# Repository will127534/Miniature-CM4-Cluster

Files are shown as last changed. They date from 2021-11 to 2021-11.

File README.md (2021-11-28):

# Miniature CM4 Cluster
A dense Cluster for four Raspberry Pi 4 Compute Module 4

Here is the main description: [https://will127534.github.io/Miniature-CM4-Cluster/](https://will127534.github.io/Miniature-CM4-Cluster/)

## System Arch


## Files
* ClusterHat - PCB files for CLuster Hat
* CM4Card - PCB files for CM4 Card
* Software - Code for Raspberry Pi Pico & I2C EEPROM image for USB Hub
* Mechanical - STL for the dual 4cm fan frame 

## Notes
* RTL8367N Datasheet comes from here https://github.com/libc0607/Realtek_switch_hacking
* Designed with KiCad 5.99.0-12597-g9f841da98e

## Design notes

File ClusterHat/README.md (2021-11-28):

# CM4-Cluster-Hat
The PCB board files for the main hat

## Notes
* The measurement of node's input current is on the CM4 Card (tps2420 efuse current monitor output)
* I tried to use GPIO pin straps to set up USB Hub, but there is no such configuration that works, so I end up placing an I2C EEPROM that contains the settings. There are three jumpers at the back of the board that connect that EEPROM to RPI & hold the reset of USB HUB, so you can/need to flash the EEPROM image the first time.
    * Also note that because reversing the polarity of USB data eases the layout, all of the device's USB polarity is swapped and configured as such, so that is why in the sch the P/N is reversed.
    * There might be some issue with the LED indicator on the USB Hub.
* You could connect the MII interface to RPI, but I'm not sure how to use it to turn it into a managed switch.
* And just to remind you that **the M.2 connector on this board is a non-standard pinout**, please don't attach anything other than the CM4 Card.
 
## Preview



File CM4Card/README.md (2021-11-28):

# CM4 Card
The PCB board files for the CM4 Card

## Notes
* Because the interconnector is using M.2, the board thickness is limited to 0.8mm
* Yes, I did put most of the components under CM4. The SD card slot is 1.45mm in height. It is fine with the 3mm connector height for the CM4.
* The address for TMP117 is depend on the Cluster Hat.

## Preview



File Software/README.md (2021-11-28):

# Software
Pico Software and USB hub EEPROM image

## Pico Software

The code is a slightly modified version of the adc_console.c from the Pico C/C++ SDK, the main changes are adding more commend to control the GPIO pins and reading current measurement.  
```
Selecting the channel/node, send c + [node number]
Enabling the power (Pull EN pin on the CM4 high), send e
Disabling the power (Pull EN pin on the CM4 low), send d
Asserting USB boot pin, send U
Disasserting USB boot pin, send u
Resetting the CM4 via RUN pin (holding it low for 100ms), send r 
Reading the ADC raw and voltage measurement, send s
Reading all the CM4's current, send a
```

## USB hub configuring

Apart from the name customization, the USB pins are configured to be flipped for all the downstream ports that are used.

To flash the binary, you can use the following command after you connect the EEPROM to RPI.
```

```

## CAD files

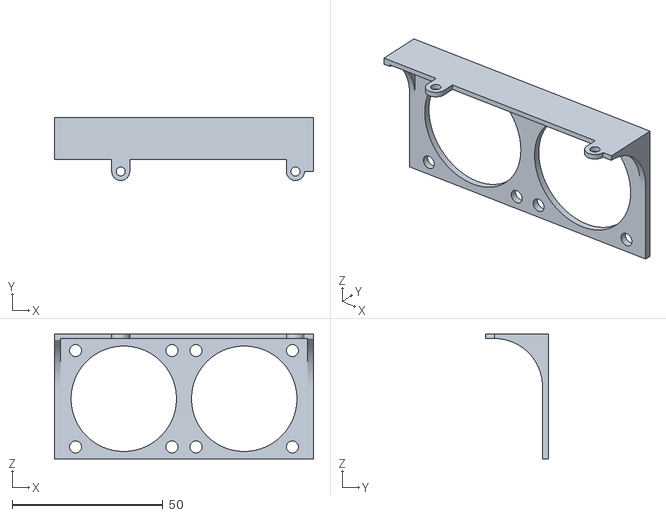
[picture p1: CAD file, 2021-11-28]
Mechanical/ClusterFan.stl
86.0 x 21.0 x 41.5

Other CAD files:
Mechanical/ClusterFan.f3d

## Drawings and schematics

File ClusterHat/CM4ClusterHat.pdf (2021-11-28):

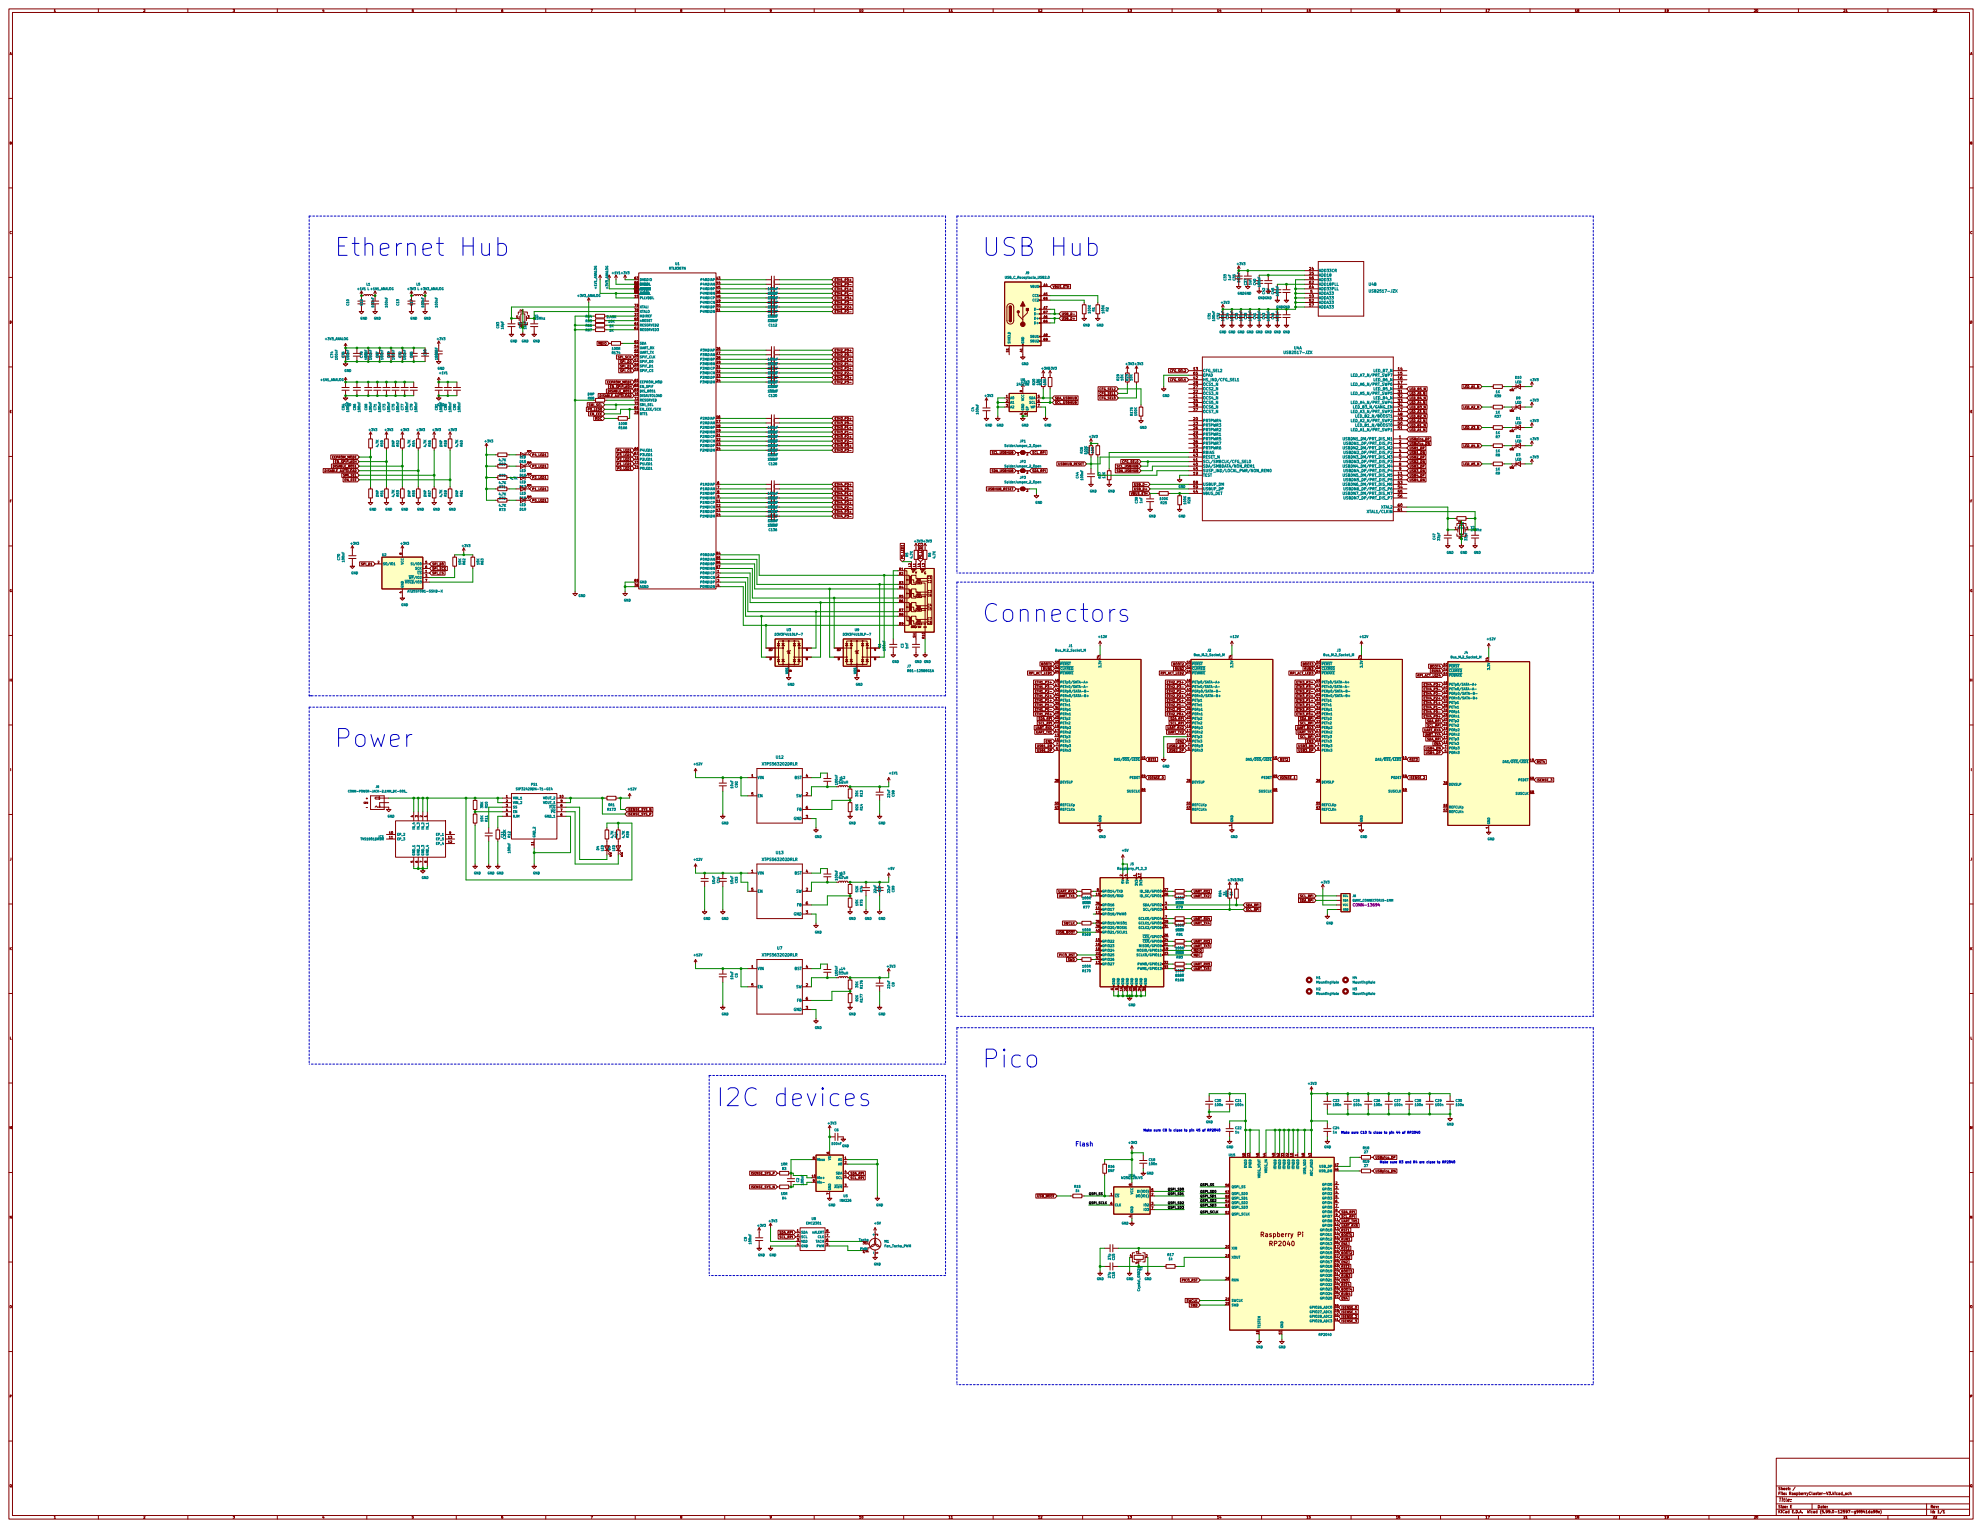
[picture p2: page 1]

LED GND GND 27p C15 GND

Make sure C8 is close to pin 45 of RP2040

Make sure C10 is close to pin 44 of RP2040

Make sure R3 and R4 are close to RP2040 Flash

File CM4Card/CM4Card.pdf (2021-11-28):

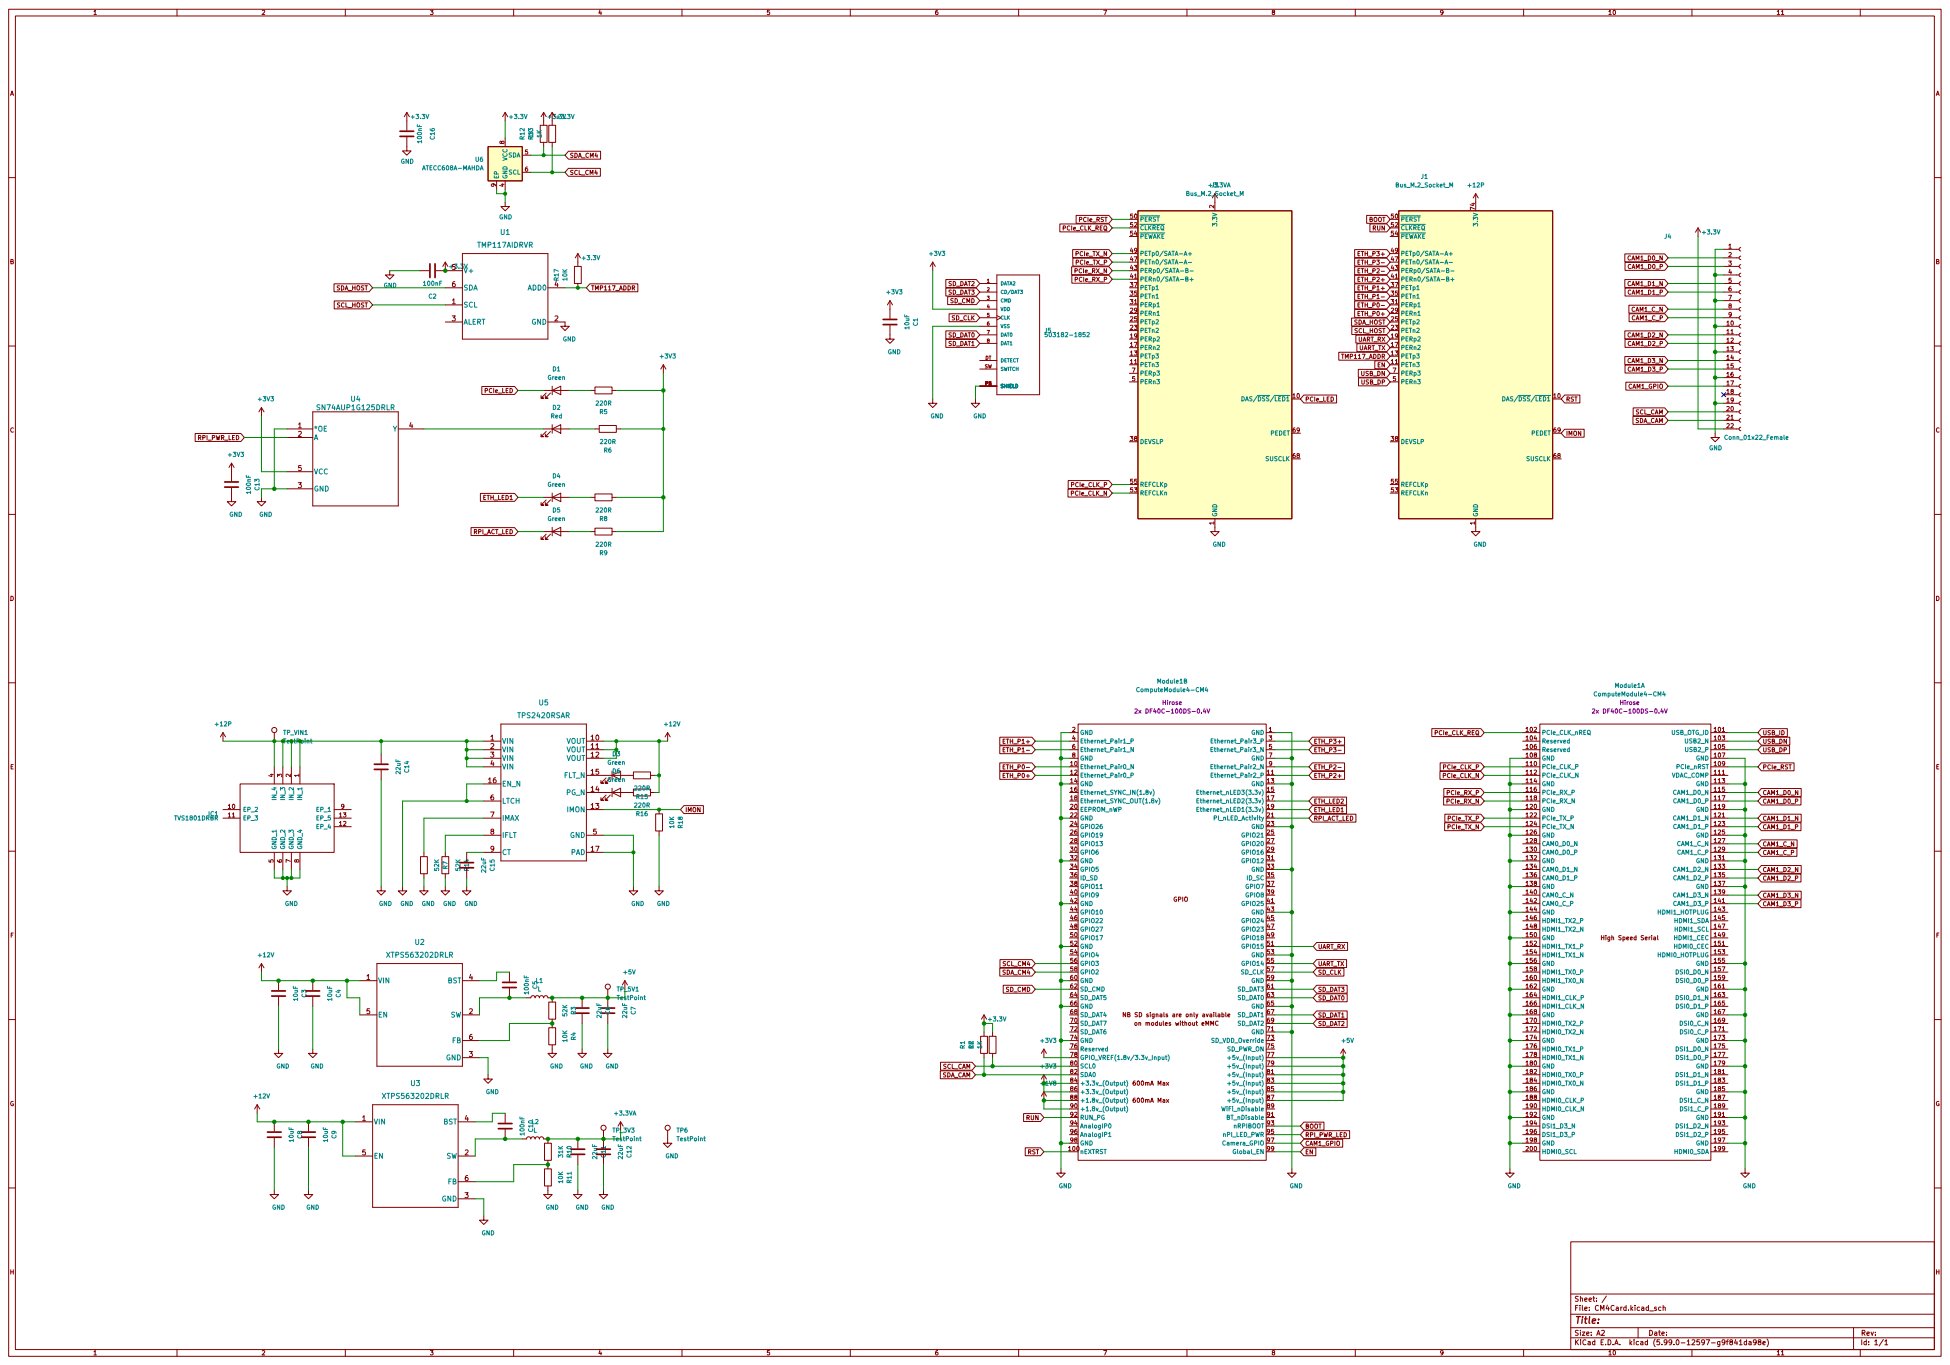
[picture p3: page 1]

2 PETn2 23 PETp2 25 PERn1 29 PERp1 31 PETn1 35 PETp1 37 DEVSLP 38 PERn0/SATA-B+ 41 PERp0/SATA-B- 43 PETn0/SATA-A- 47 PETp0/SATA-A+ 49 PERn3 5 ~{PERST} 50 ~{CLKREQ} 52 REFCLKn 53

600mA Max 600mA Max NB SD signals are only available

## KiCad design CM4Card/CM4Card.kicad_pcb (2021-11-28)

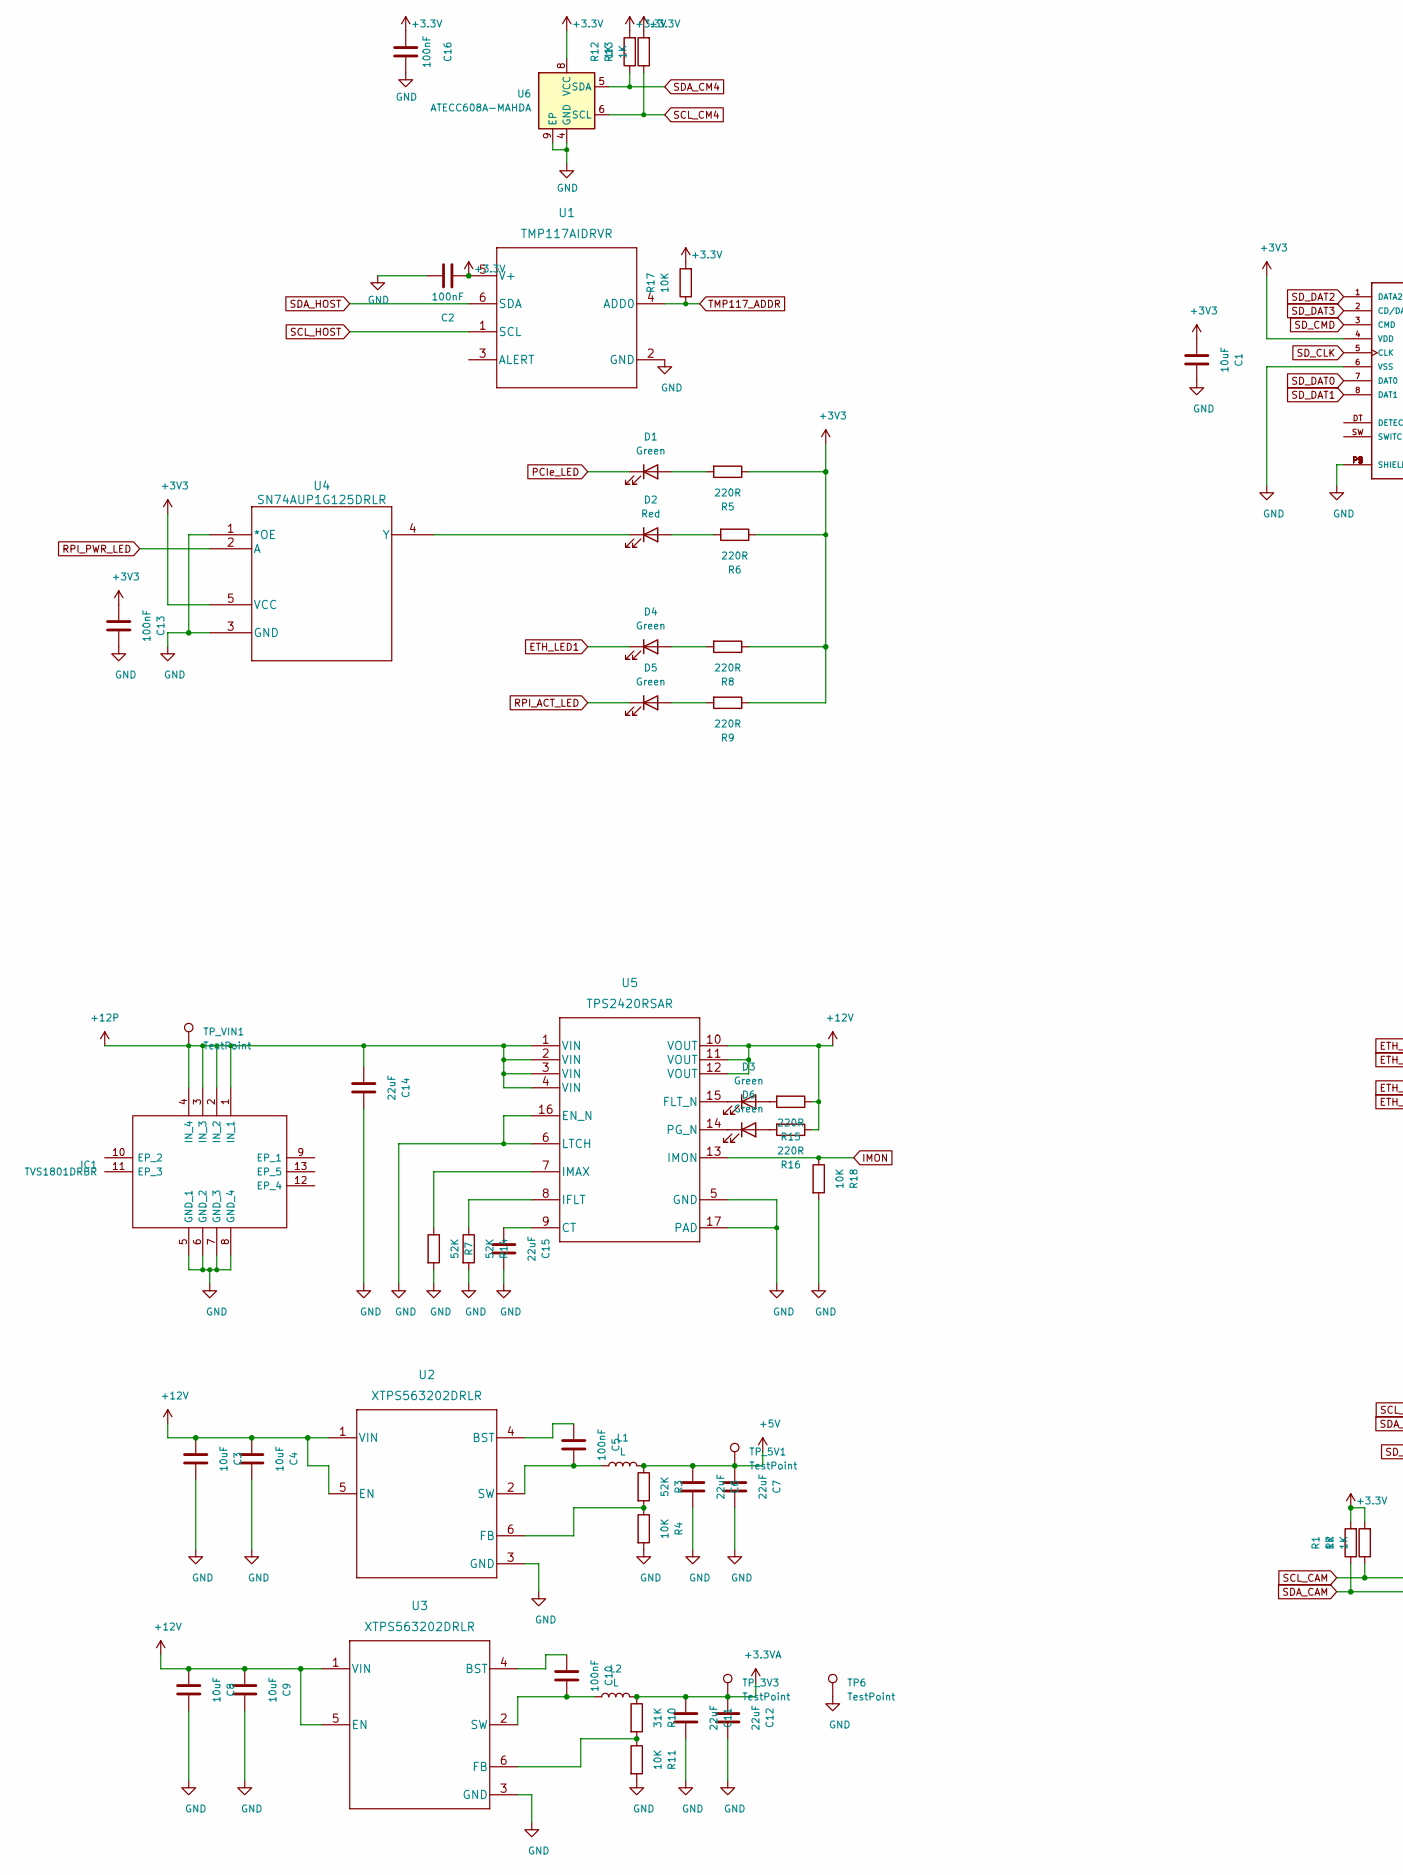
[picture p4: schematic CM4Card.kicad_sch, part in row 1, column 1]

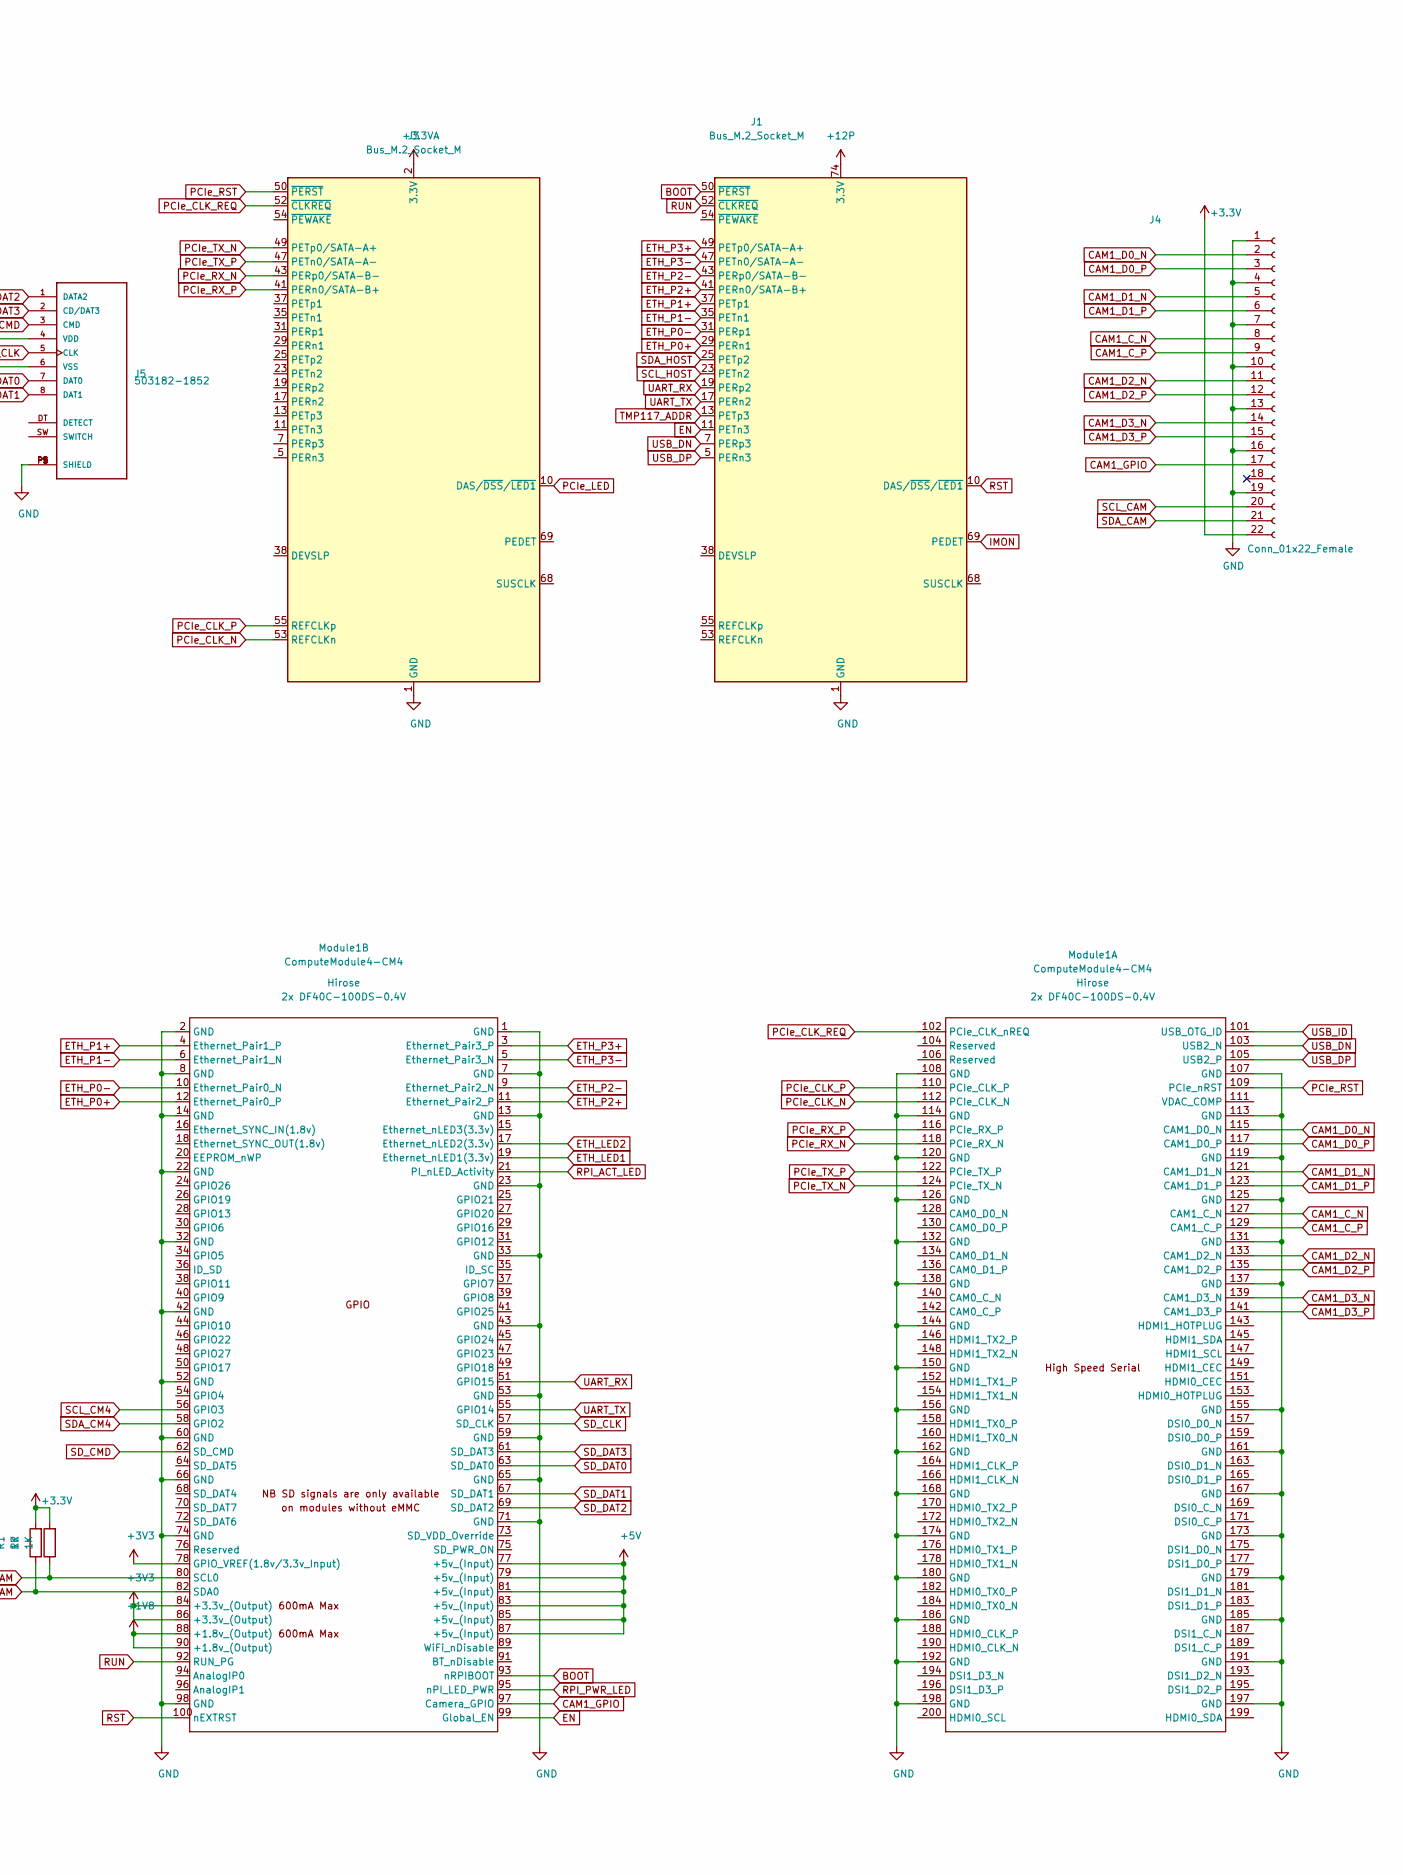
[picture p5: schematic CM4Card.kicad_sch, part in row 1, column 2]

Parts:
C1, C3, C4, C8, C9: 10uF; C_0805_2012Metric
C2, C5, C10, C13, C16: 100nF; C_0402_1005Metric
C6, C7, C11, C12: 22uF; C_0805_2012Metric
C14, C15: 22uF; C_0402_1005Metric
D1, D3, D4, D5, D6: Green; LED_0603_1608Metric
D2: Red; LED_0603_1608Metric
IC1: TVS1801DRBR; TPS73601DRBR; Mouser Part Number 595-TVS1801DRBR
J1: Bus_M.2_Socket_M; NGFF_M
J3: Bus_M.2_Socket_M; 1-2199230-6
J4: Conn_01x22_Female; Hirose_FH12-22S-0.5SH_1x22-1MP_P0.50mm_Horizontal; Part Description 22 Position FFC, FPC Connector Contacts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
J5: 503182-1852; MOLEX_503182-1852
L1, L2: L; L_Coilcraft_XAL5030
Module1: ComputeModule4-CM4; Raspberry-Pi-4-Compute-Module
R1, R2, R12, R13: 1K; R_0402_1005Metric
R3, R7, R14: 52K; R_0402_1005Metric
R4, R11, R17, R18: 10K; R_0402_1005Metric
R5, R6, R8, R9, R15, R16: 220R; R_0402_1005Metric
R10: 31K; R_0402_1005Metric
TP6: TestPoint; TestPoint_Pad_D2.0mm
TP_3V3, TP_5V1: TestPoint; TestPoint_Pad_D2.0mm
TP_VIN1: TestPoint; TestPoint_Pad_D2.0mm
U1: TMP117AIDRVR
U2, U3: XTPS563202DRLR
U4: SN74AUP1G125DRLR
U5: TPS2420RSAR
U6: ATECC608A-MAHDA; DFN-8-1EP_3x2mm_P0.5mm_EP1.3x1.5mm

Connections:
+1V8: Module1.88 (+1.8v_(Output)), Module1.90 (+1.8v_(Output))
+3.3VA: C11.1, C12.1, J3.2 (3.3V), J3.4 (3.3V), J3.12 (3.3V), J3.14 (3.3V), J3.16 (3.3V), J3.18 (3.3V), J3.70 (3.3V), J3.72 (3.3V), J3.74 (3.3V), L2.2, R10.1, TP_3V3.1
+5V: C6.1, C7.1, L1.2, Module1.77 (+5v_(Input)), Module1.79 (+5v_(Input)), Module1.81 (+5v_(Input)), Module1.83 (+5v_(Input)), Module1.85 (+5v_(Input)), Module1.87 (+5v_(Input)), R3.1, TP_5V1.1
+12P: C14.1, IC1.1 (IN_1), IC1.2 (IN_2), IC1.3 (IN_3), IC1.4 (IN_4), J1.70 (3.3V), J1.72 (3.3V), J1.74 (3.3V), TP_VIN1.1, U5.1 (VIN), U5.2 (VIN), U5.3 (VIN), U5.4 (VIN)
+12V: C3.1, C4.1, C8.1, C9.1, R15.1, R16.1, U2.1 (VIN), U2.5 (EN), U3.1 (VIN), U3.5 (EN), U5.10 (VOUT), U5.11 (VOUT), U5.12 (VOUT)
BOOT: J1.50 (~PERST), Module1.93 (nRPIBOOT)
CAM1_C_N: J4.8, Module1.127 (CAM1_C_N)
CAM1_C_P: J4.9, Module1.129 (CAM1_C_P)
CAM1_D0_N: J4.2, Module1.115 (CAM1_D0_N)
CAM1_D0_P: J4.3, Module1.117 (CAM1_D0_P)
CAM1_D1_N: J4.5, Module1.121 (CAM1_D1_N)
CAM1_D1_P: J4.6, Module1.123 (CAM1_D1_P)
CAM1_D2_N: J4.11, Module1.133 (CAM1_D2_N)
CAM1_D2_P: J4.12, Module1.135 (CAM1_D2_P)
CAM1_D3_N: J4.14, Module1.139 (CAM1_D3_N)
CAM1_D3_P: J4.15, Module1.141 (CAM1_D3_P)
CAM1_GPIO: J4.17, Module1.97 (Camera_GPIO)
EN: J1.11 (PETn3), Module1.99 (Global_EN)
ETH_LED1: D4.1 (K), Module1.19 (Ethernet_nLED1(3.3v))
ETH_LED2: Module1.17 (Ethernet_nLED2(3.3v))
ETH_P0+: J1.29 (PERn1), Module1.12 (Ethernet_Pair0_P)
ETH_P0-: J1.31 (PERp1), Module1.10 (Ethernet_Pair0_N)
ETH_P1+: J1.37 (PETp1), Module1.4 (Ethernet_Pair1_P)
ETH_P1-: J1.35 (PETn1), Module1.6 (Ethernet_Pair1_N)
ETH_P2+: J1.41 (PERn0/SATA-B+), Module1.11 (Ethernet_Pair2_P)
ETH_P2-: J1.43 (PERp0/SATA-B-), Module1.9 (Ethernet_Pair2_N)
ETH_P3+: J1.49 (PETp0/SATA-A+), Module1.3 (Ethernet_Pair3_P)
ETH_P3-: J1.47 (PETn0/SATA-A-), Module1.5 (Ethernet_Pair3_N)
GND: C1.2, C2.2, C3.2, C4.2, C6.2, C7.2, C8.2, C9.2, C11.2, C12.2, C13.2, C14.2, C15.2, C16.2, IC1.5 (GND_1), IC1.6 (GND_2), IC1.7 (GND_3), IC1.8 (GND_4), J1.1 (GND), J1.3 (GND), J1.9 (GND), J1.15 (GND), J1.21 (GND), J1.27 (GND), J1.33 (GND), J1.39 (GND), J1.45 (GND), J1.51 (GND), J1.57 (GND), J1.71 (GND), J1.73 (GND), J1.75 (GND), J3.1 (GND), J3.3 (GND), J3.9 (GND), J3.15 (GND), J3.21 (GND), J3.27 (GND), J3.33 (GND), J3.39 (GND), J3.45 (GND), J3.51 (GND), J3.57 (GND), J3.71 (GND), J3.73 (GND), J3.75 (GND), J4.1, J4.4, J4.7, J4.10, J4.13, J4.16, J4.19, J5.6 (VSS), J5.P1 (SHIELD), J5.P2 (SHIELD), J5.P3 (SHIELD), J5.P4 (SHIELD), J5.P5 (SHIELD), Module1.1 (GND), Module1.2 (GND), Module1.7 (GND), Module1.8 (GND), Module1.13 (GND), Module1.14 (GND), Module1.22 (GND), Module1.23 (GND), Module1.32 (GND), Module1.33 (GND), Module1.42 (GND), Module1.43 (GND), Module1.52 (GND), Module1.53 (GND), Module1.59 (GND), Module1.60 (GND), Module1.65 (GND), Module1.66 (GND), Module1.71 (GND), Module1.74 (GND), Module1.98 (GND), Module1.107 (GND), Module1.108 (GND), Module1.113 (GND), Module1.114 (GND), Module1.119 (GND), Module1.120 (GND), Module1.125 (GND), Module1.126 (GND), Module1.131 (GND), Module1.132 (GND), Module1.137 (GND), Module1.138 (GND), Module1.144 (GND), Module1.150 (GND), Module1.155 (GND), Module1.156 (GND), Module1.161 (GND), Module1.162 (GND), Module1.167 (GND), Module1.168 (GND), Module1.173 (GND), Module1.174 (GND), Module1.179 (GND), Module1.180 (GND), Module1.185 (GND), Module1.186 (GND), Module1.191 (GND), Module1.192 (GND), Module1.197 (GND), Module1.198 (GND), R4.2, R7.2, R11.2, R14.2, R18.2, TP6.1, U1.2 (GND), U2.3 (GND), U3.3 (GND), U4.1 (*OE), U4.3 (GND), U5.5 (GND), U5.6 (LTCH), U5.16 (EN_N), U5.17 (PAD), U6.4 (GND), U6.9 (EP)
IMON: J1.69 (PEDET), R18.1, U5.13 (IMON)
unnamed: C5.1, U2.4 (BST)
unnamed: C5.2, L1.1, U2.2 (SW)
unnamed: C10.1, U3.4 (BST)
unnamed: C10.2, L2.1, U3.2 (SW)
unnamed: C15.1, U5.9 (CT)
unnamed: D1.2 (A), R5.2
unnamed: D2.1 (K), U4.4 (Y)
unnamed: D2.2 (A), R6.2
unnamed: D3.1 (K), U5.15 (FLT_N)
unnamed: D3.2 (A), R15.2
unnamed: D4.2 (A), R8.2
unnamed: D5.2 (A), R9.2
unnamed: D6.1 (K), U5.14 (PG_N)
unnamed: D6.2 (A), R16.2
unnamed: R3.2, R4.1, U2.6 (FB)
unnamed: R7.1, U5.7 (IMAX)
unnamed: R10.2, R11.1, U3.6 (FB)
unnamed: R14.1, U5.8 (IFLT)
PCIe_CLK_N: J3.53 (REFCLKn), Module1.112 (PCIe_CLK_N)
PCIe_CLK_P: J3.55 (REFCLKp), Module1.110 (PCIe_CLK_P)
PCIe_CLK_REQ: J3.52 (~CLKREQ), Module1.102 (PCIe_CLK_nREQ)
PCIe_LED: D1.1 (K), J3.10 (DAS/~DSS/~LED1)
PCIe_RST: J3.50 (~PERST), Module1.109 (PCIe_nRST)
PCIe_RX_N: J3.43 (PERp0/SATA-B-), Module1.118 (PCIe_RX_N)
PCIe_RX_P: J3.41 (PERn0/SATA-B+), Module1.116 (PCIe_RX_P)
PCIe_TX_N: J3.49 (PETp0/SATA-A+), Module1.124 (PCIe_TX_N)
PCIe_TX_P: J3.47 (PETn0/SATA-A-), Module1.122 (PCIe_TX_P)
RPI_ACT_LED: D5.1 (K), Module1.21 (PI_nLED_Activity)
RPI_PWR_LED: Module1.95 (nPI_LED_PWR), U4.2 (A)
RST: J1.10 (DAS/~DSS/~LED1), Module1.100 (nEXTRST)
RUN: J1.52 (~CLKREQ), Module1.92 (RUN_PG)
SCL_CAM: J4.20, Module1.80 (SCL0), R2.1
SCL_CM4: Module1.56 (GPIO3), R13.1, U6.6 (SCL)
SCL_HOST: J1.23 (PETn2), U1.1 (SCL)
SDA_CAM: J4.21, Module1.82 (SDA0), R1.1
SDA_CM4: Module1.58 (GPIO2), R12.1, U6.5 (SDA)
SDA_HOST: J1.25 (PETp2), U1.6 (SDA)
SD_CLK: J5.5 (CLK), Module1.57 (SD_CLK)
SD_CMD: J5.3 (CMD), Module1.62 (SD_CMD)
SD_DAT0: J5.7 (DAT0), Module1.63 (SD_DAT0)
SD_DAT1: J5.8 (DAT1), Module1.67 (SD_DAT1)
SD_DAT2: J5.1 (DATA2), Module1.69 (SD_DAT2)
SD_DAT3: J5.2 (CD/DAT3), Module1.61 (SD_DAT3)
TMP117_ADDR: J1.13 (PETp3), R17.1, U1.4 (ADD0)
UART_RX: J1.19 (PERp2), Module1.51 (GPIO15)
UART_TX: J1.17 (PERn2), Module1.55 (GPIO14)
USB_DN: J1.7 (PERp3), Module1.103 (USB2_N)
USB_DP: J1.5 (PERn3), Module1.105 (USB2_P)
USB_ID: Module1.101 (USB_OTG_ID)

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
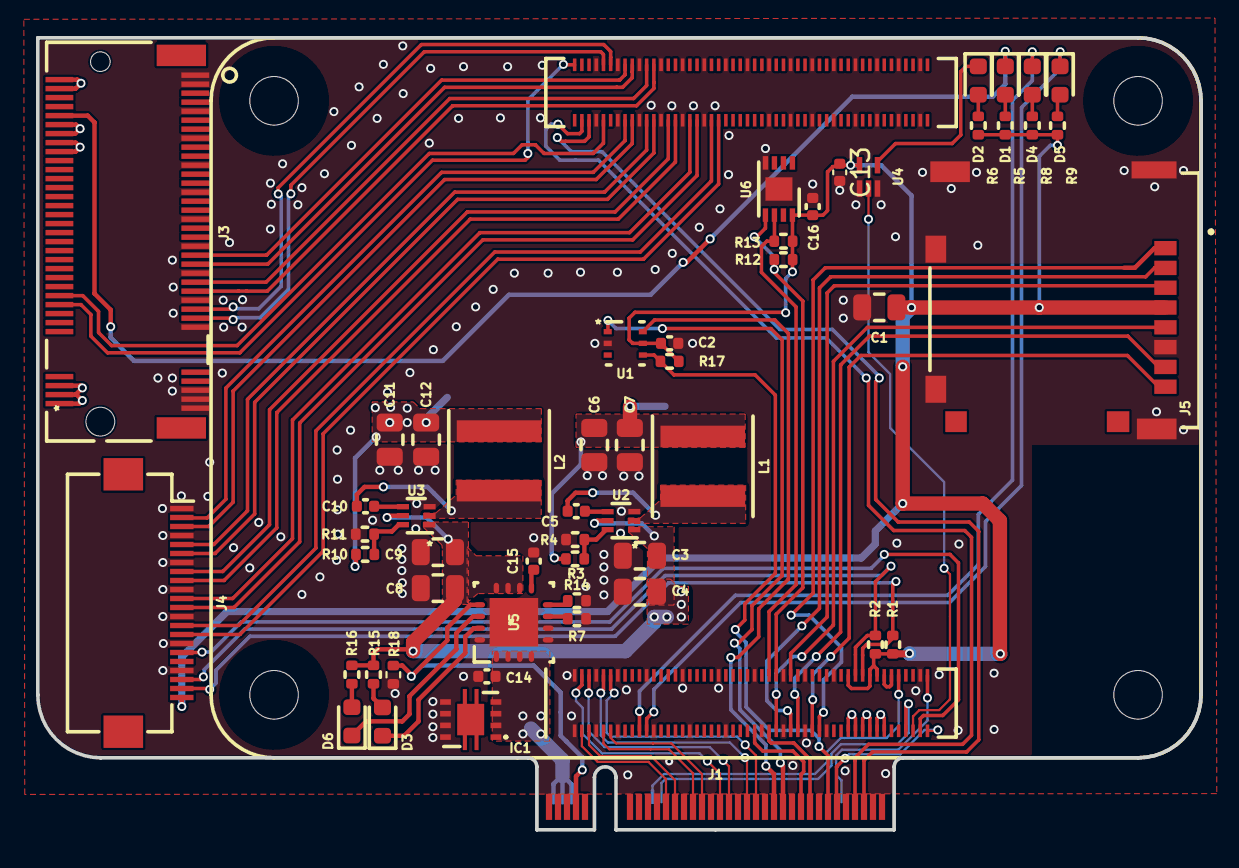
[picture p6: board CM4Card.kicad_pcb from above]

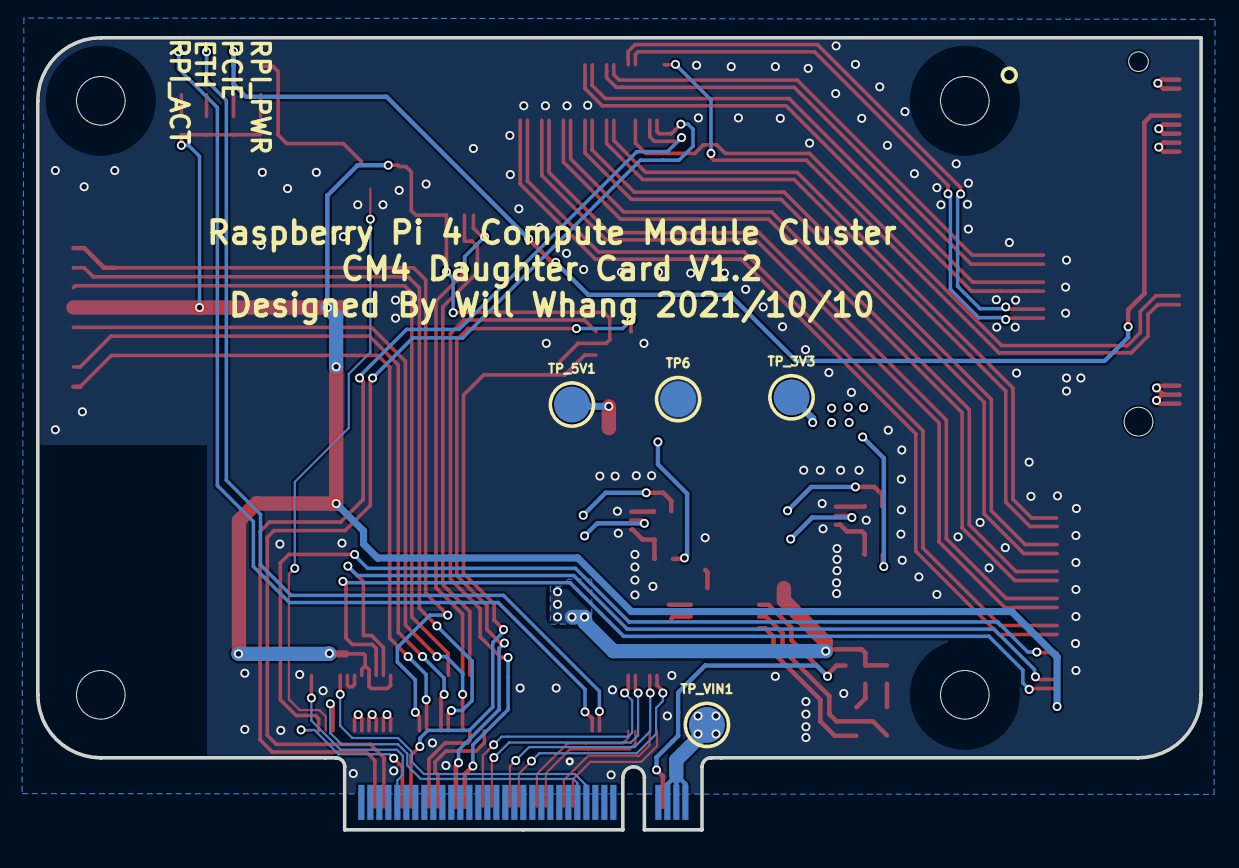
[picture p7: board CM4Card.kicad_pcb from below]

Board: 4 copper layers, 64.6 x 44.0 mm, 58 parts (4 on the bottom side), 78 nets.

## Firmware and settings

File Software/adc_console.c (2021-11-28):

#include <stdio.h>
#include "pico/stdlib.h"
#include "hardware/gpio.h"
#include "hardware/adc.h"

#define N_SAMPLES 1000
uint16_t sample_buf[N_SAMPLES];

#define RST1 10
#define RST2 14
#define RST3 18
#define RST4 22

#define EN1 13
#define EN2 17
#define EN3 21
#define EN4 25

#define RUN1 12
#define RUN2 16
#define RUN3 20
#define RUN4 24

#define BOOT1 11
#define BOOT2 15
#define BOOT3 19
#define BOOT4 23

uint8_t Reset[4] = {RST1,RST2,RST3,RST4};
uint8_t Enable[4] = {EN1,EN2,EN3,EN4};
uint8_t Run[4] = {RUN1,RUN2,RUN3,RUN4};
uint8_t Boot[4] = {BOOT1,BOOT2,BOOT3,BOOT4};

void printhelp() {
    puts("\nCommands:");
    puts("c0, ...\t: Select CM4 channel n");
    puts("s\t: Sample once");
    puts("r\t: Reset CM4");
    puts("U\t: Assert USB Boot");
    puts("u\t: Deassert USB Boot");
    puts("e\t: Enable power");
    puts("d\t: Disable power");
    puts("a\t: Sample all CM4 current measurements");


}

void __not_in_flash_func(adc_capture)(uint16_t *buf, size_t count) {
    adc_fifo_setup(true, false, 0, false, false);
    adc_run(true);
    for (int i = 0; i < count; i = i + 1)
        buf[i] = adc_fifo_get_blocking();
    adc_run(false);
    adc_fifo_drain();
}

int main(void) {

    // Set all pins to input (as far as SIO is concerned)
    //gpio_set_dir_all_bits(-1);
    for (int i = 0; i < 4; ++i){
        gpio_init(Reset[i]);
        gpio_init(Enable[i]);
        gpio_init(Run[i]);
        gpio_init(Boot[i]);

        gpio_set_dir(Reset[i],GPIO_IN);
        gpio_set_dir(Enable[i],GPIO_OUT);
        gpio_set_dir(Run[i],GPIO_OUT);
        gpio_set_dir(Boot[i],GPIO_OUT);

        //gpio_put(Reset[i],1);
        gpio_put(Enable[i],0);
        gpio_put(Run[i],1);
        gpio_put(Boot[i],1);
    }

    for (int i = 26; i < 30; ++i){
        gpio_init(i);
    }


    stdio_init_all();
    adc_init();
    adc_set_temp_sensor_enabled(true);

    uint8_t channel = 0;
    while (1) {
        char c = getchar();
        printf("%c", c);
        switch (c) {
            case 'c':
                c = getchar(); 
                printf("%c\n", c);
                if (c < '0' || c > '3') {
                    printf("Unknown input channel\n");
                    printhelp();
                } else {
                    adc_select_input(c - '0');
                    printf("Switched to channel %c\n", c);
                    channel = c - '0';
                }
                break;
            case 'r': {
                gpio_put(Run[channel],0);
                sleep_ms(100);
                gpio_put(Run[channel],1);
                printf("Reseting:%d\n", channel);
                break;
            }
            case 'u': {
                gpio_put(Boot[channel],1);
                printf("USB boot deassert:%d\n", channel);
                break;
            }
            case 'U': {
                gpio_put(Boot[channel],0);
                printf("USB boot assert:%d\n", channel);
                break;
            }
            case 'd': {
                gpio_put(Enable[channel],0);
                printf("Disable:%d\n", channel);
                break;
            }
            case 'e': {
                gpio_put(Enable[channel],1);
                printf("Enable:%d\n", channel);
                break;
            }
            case 's': {
                uint32_t result = adc_read();
                const float conversion_factor = 3.3f / (1 << 12);
                printf("\n0x%03x -> %f V\n", result, result * conversion_factor);
                break;
            }
            case 'a': {
                adc_select_input(0);
                adc_capture(sample_buf, N_SAMPLES);
                double result_ch0 = 0;
                for (int i = 0; i < N_SAMPLES; i = i + 1)
                    result_ch0 += sample_buf[i]/1000.0;
                adc_select_input(1);
                adc_capture(sample_buf, N_SAMPLES);
                double result_ch1 = 0;
                for (int i = 0; i < N_SAMPLES; i = i + 1)
                    result_ch1 += sample_buf[i]/1000.0;
                adc_select_input(2);
                adc_capture(sample_buf, N_SAMPLES);
                double result_ch2 = 0;
                for (int i = 0; i < N_SAMPLES; i = i + 1)
                    result_ch2 += sample_buf[i]/1000.0;
                adc_select_input(3);
                adc_capture(sample_buf, N_SAMPLES);
                double result_ch3 = 0;
                for (int i = 0; i < N_SAMPLES; i = i + 1)
                    result_ch3 += sample_buf[i]/1000.0;
                const float conversion_factor = 3.3f / (1 << 12) * 1000.0;
                printf("\n%f mA,%f mA,%f mA,%f mA\n", result_ch0 * conversion_factor, result_ch1 * conversion_factor, result_ch2 * conversion_factor, result_ch3 * conversion_factor);
                adc_select_input(channel);
                break;
            }
            case 'S': {
                printf("\nStarting capture\n");
                adc_capture(sample_buf, N_SAMPLES);
                printf("Done\n");
                for (int i = 0; i < N_SAMPLES; i = i + 1)
                    printf("%03x\n", sample_buf[i]);
                break;
            }
            case '\n':
            case '\r':
                break;
            case 'h':
                printhelp();
                break;
            default:
                printf("\nUnrecognised command: %c\n", c);
                printhelp();
                break;
        }
    }
}

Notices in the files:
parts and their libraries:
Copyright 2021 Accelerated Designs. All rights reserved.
